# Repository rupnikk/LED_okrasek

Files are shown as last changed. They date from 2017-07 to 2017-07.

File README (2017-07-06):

Urban Rupnik
Zadlog 42
LED_okrasek

-------------------------------------------------------

PCB verzija 1.1 (december 2016)

********SPREMEMBE************
- dovolj velik procesor(ne vem koliko prostora bodo zasedle melodije, tudi zaradi I2C in USART)
- IR oddajnik in sprejemnik (za 36 kHz in 38 kHz)
- en input gumb
- 8 led 
- 1W ojačevalnik
- zvočnik
- porti povezani precej naključno (en prvih tudi programerskih projektov)

PCB verzija 1.2 (januar 2017)
- dovolj velik procesor(ne vem koliko prostora bodo zasedle melodije)
- IR oddajnik in sprejemnik (za 36 kHz in 38 kHz)
- en input gumb
- 8 led 
- 1W ojačevalnik
- zvočnik

********SPREMEMBE************
- BTN na pin 32 (tam je možnost INT, ne samo PCINT)
- IR_REC na pin 1 (tam je možnost INT, ne samo PCINT)
- IR_LED na pin 15 (PB3)(OC2A)(niso iste nastavitve kot pri timerju-0 za AUDIO))(ne na pin 11, zato ker se nastavitev timerja 1 ne bodo mogle prilagajat, zaradi branja daljinca)
-prilagoditev LED-ic

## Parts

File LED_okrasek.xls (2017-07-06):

Reference | Value | Footprint | Datasheet | Farnelll number | Farnell number
LS1 | speaker | LED_okrasek:Speaker | http://www.newark.com/pdfs/datasheets/spc/25R0902.pdf?_ga=1.246424708.1660152525.1481320514 | 2396077
U2 | NCP2890DMR2G | LED_okrasek:Micro8_SMD | http://www.farnell.com/datasheets/1878956.pdf?_ga=1.155430843.1660152525.1481320514 |  | 2464740
C4 | 1u | LED_okrasek:C_0603_HandSoldering
R12 | 10k | LED_okrasek:R_0603_HandSoldering
IC1 | ATMEGA328-A | LED_okrasek:TQFP-32_7x7mm_Pitch0.8mm | http://www.farnell.com/datasheets/2047852.pdf?_ga=1.212856084.1660152525.1481320514 |  | 2443176
R7 | 10k | LED_okrasek:R_0603_HandSoldering
C3 | 1u | LED_okrasek:C_0603_HandSoldering
C2 | 100n | LED_okrasek:C_0603_HandSoldering
R5 | 220 | LED_okrasek:R_0603_HandSoldering
C5 | 1u | LED_okrasek:R_0603_HandSoldering
D2 | LED_Small | LED_okrasek:LED_0_1inch
D3 | LED_Small | LED_okrasek:LED_0_1inch
D4 | LED_Small | LED_okrasek:LED_0_1inch
D5 | LED_Small | LED_okrasek:LED_0_1inch
D9 | LED_Small | LED_okrasek:LED_0_1inch
D6 | LED_Small | LED_okrasek:LED_0_1inch
D7 | LED_Small | LED_okrasek:LED_0_1inch
D8 | LED_Small | LED_okrasek:LED_0_1inch
R6 | 220 | LED_okrasek:R_0603_HandSoldering
R8 | 220 | LED_okrasek:R_0603_HandSoldering
R9 | 220 | LED_okrasek:R_0603_HandSoldering
R11 | 220 | LED_okrasek:R_0603_HandSoldering
R14 | 220 | LED_okrasek:R_0603_HandSoldering
R15 | 220 | LED_okrasek:R_0603_HandSoldering
R16 | 220 | LED_okrasek:R_0603_HandSoldering
R17 | 220 | LED_okrasek:R_0603_HandSoldering
P1 | CONN_01X02 | LED_okrasek:CONN_2x1x5.08
SW1 | SW_PUSH | LED_okrasek:TACTILE_SWTICH_4PIN_SMD | http://www.farnell.com/datasheets/1914518.pdf?_ga=1.147566519.1660152525.1481320514 |  | 2320087
R10 | 220 | LED_okrasek:R_0603_HandSoldering
R13 | 10k | LED_okrasek:R_0603_HandSoldering
PAD1 | PAD | LED_okrasek:PAD
PAD2 | PAD | LED_okrasek:PAD
PAD3 | PAD | LED_okrasek:PAD
D1 | LED_Small | LED_okrasek:R_0805_HandSoldering | http://www.farnell.com/datasheets/1683589.pdf?_ga=1.208456722.1660152525.1481320514 |  | 2290428
R3 | 190 | LED_okrasek:R_0603_HandSoldering
R1 | 1k | LED_okrasek:R_0603_HandSoldering
Q1 | Q_NPN_BEC | LED_okrasek:SOT-23_Handsoldering | http://www.farnell.com/datasheets/1511859.pdf?_ga=1.180667303.1660152525.1481320514 |  | 8737070
PAD4 | PAD | LED_okrasek:PAD
U1 | IR_RECEIVER | LED_okrasek:TSOP | http://www.farnell.com/datasheets/2049972.pdf?_ga=1.122547339.1660152525.1481320514 |  | 2251356
R2 | 220 | LED_okrasek:R_0603_HandSoldering
C1 | 1u | LED_okrasek:C_0603_HandSoldering
R4 | 500 | LED_okrasek:R_0603_HandSoldering
C6 | 1u | LED_okrasek:C_0603_HandSoldering

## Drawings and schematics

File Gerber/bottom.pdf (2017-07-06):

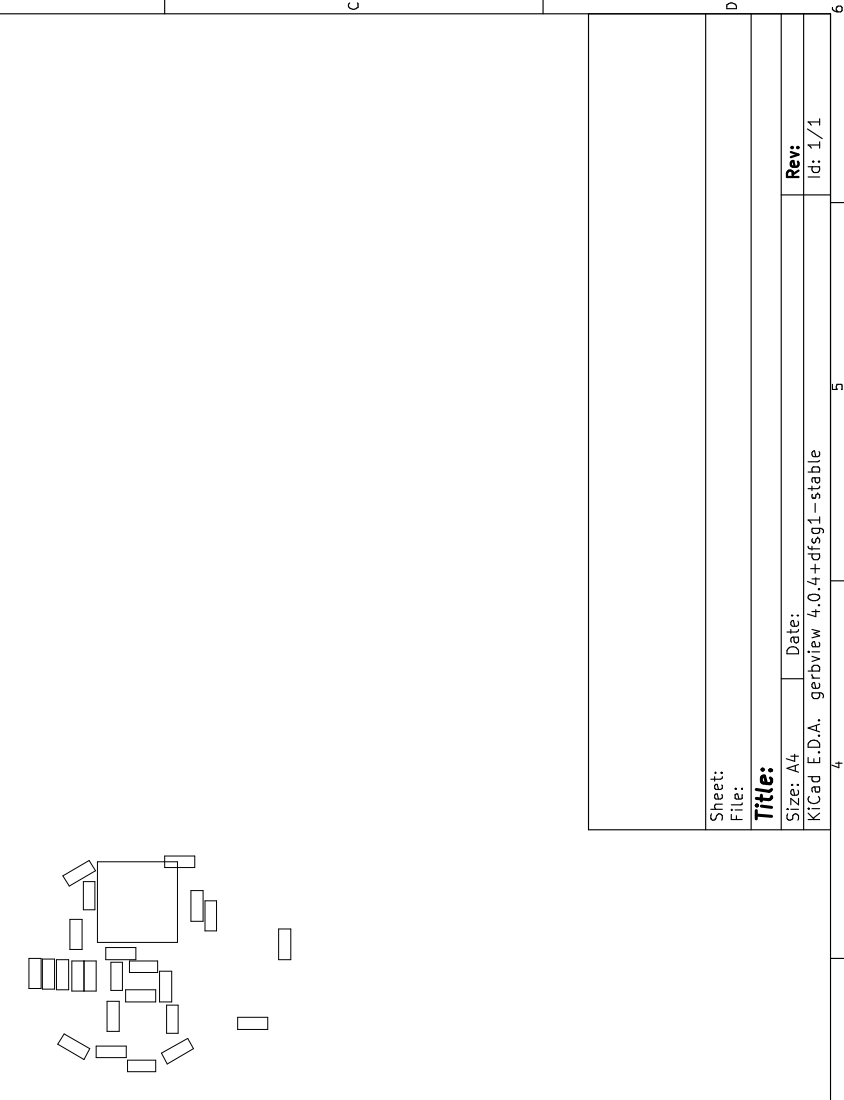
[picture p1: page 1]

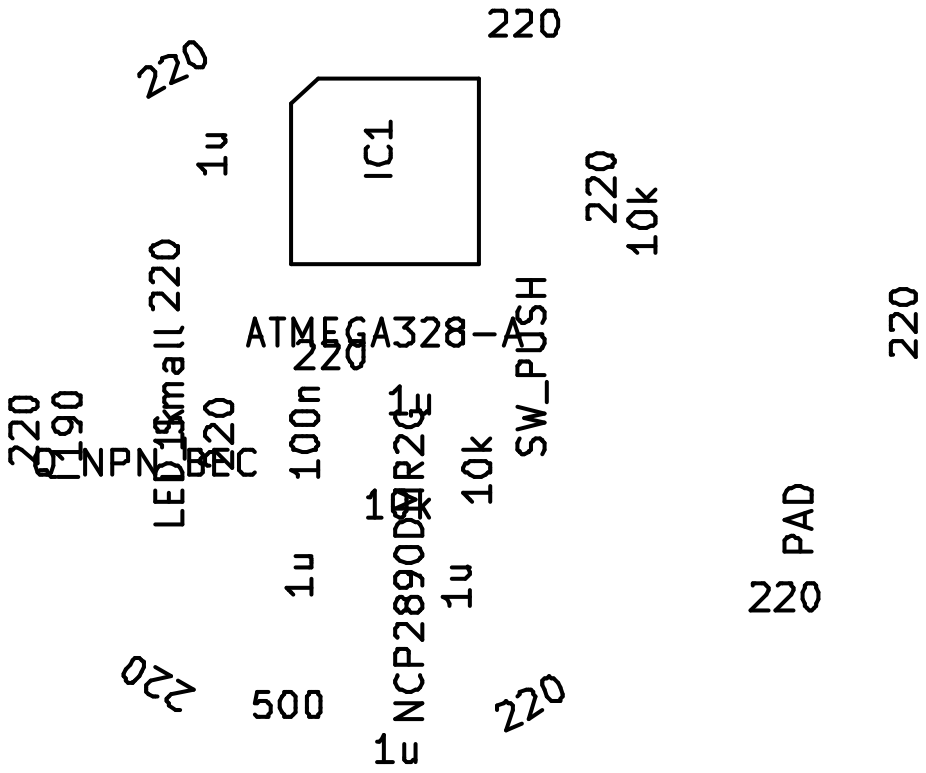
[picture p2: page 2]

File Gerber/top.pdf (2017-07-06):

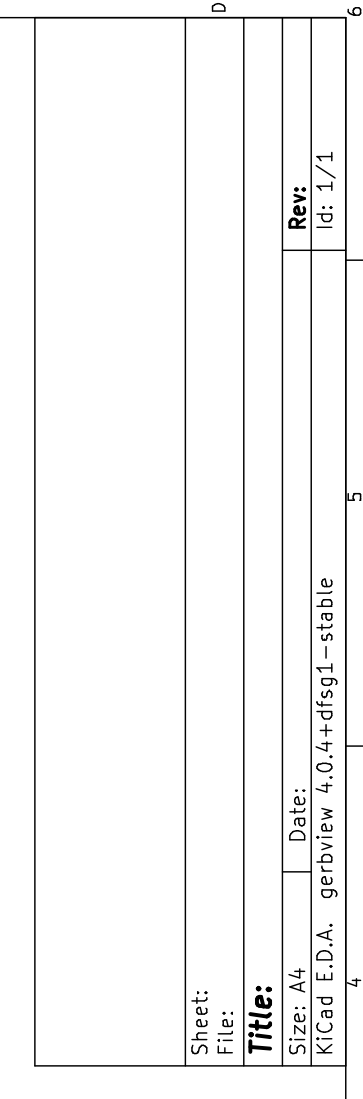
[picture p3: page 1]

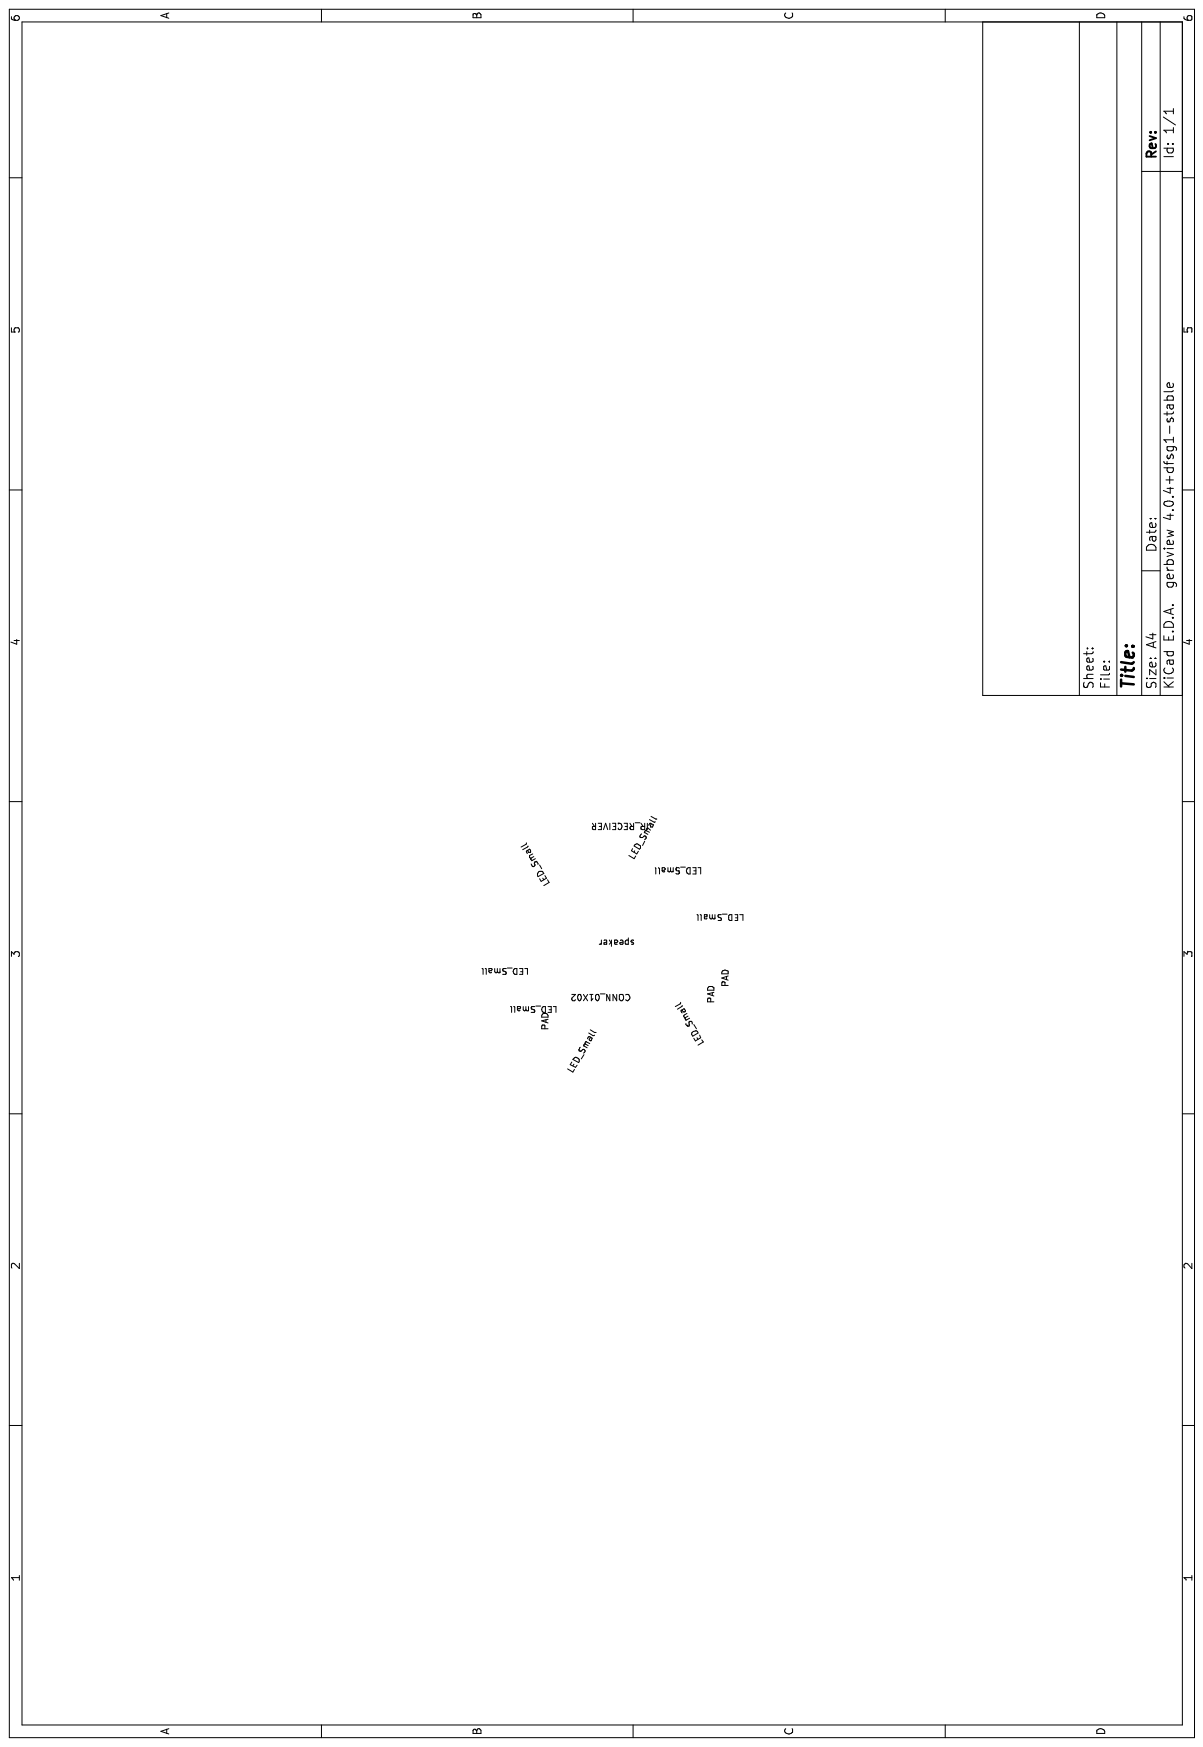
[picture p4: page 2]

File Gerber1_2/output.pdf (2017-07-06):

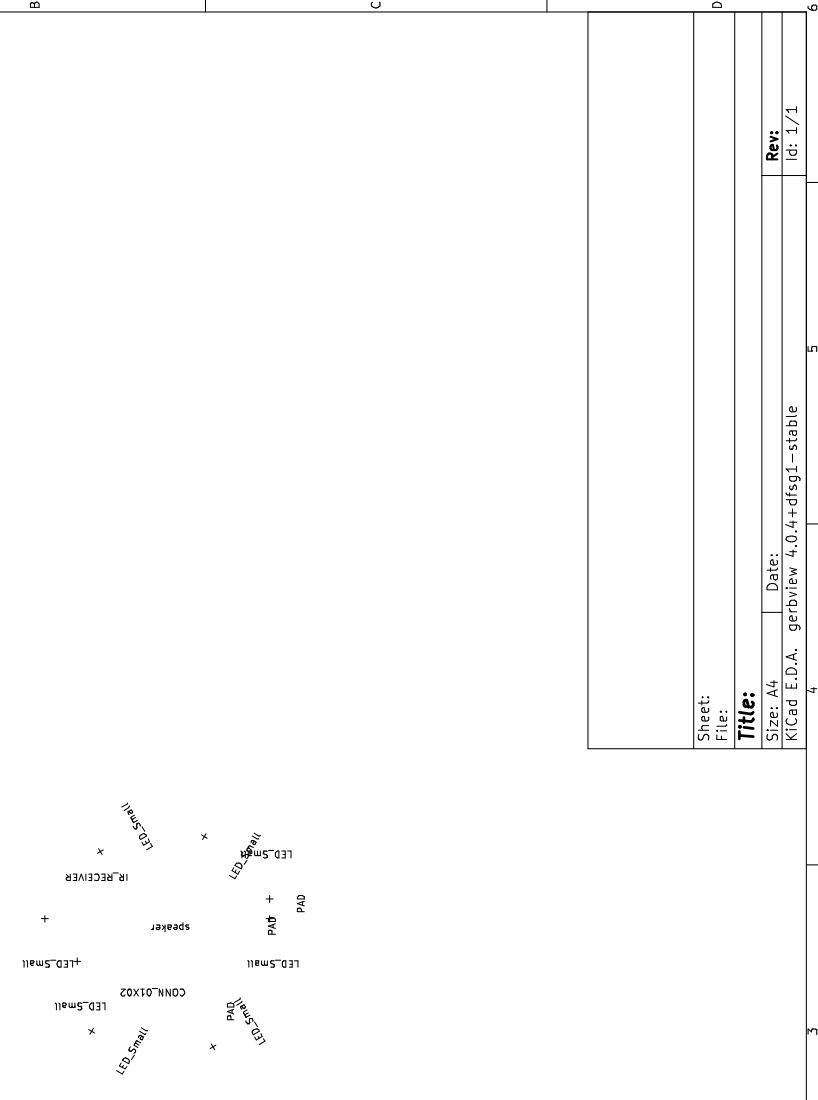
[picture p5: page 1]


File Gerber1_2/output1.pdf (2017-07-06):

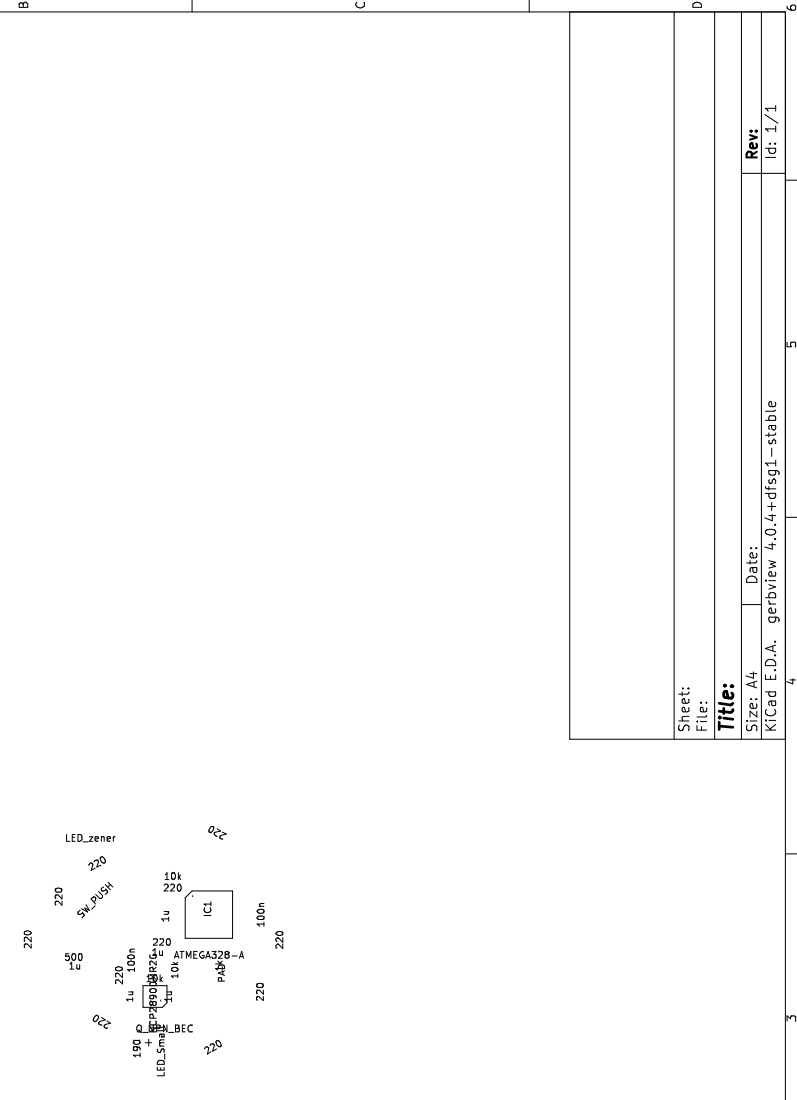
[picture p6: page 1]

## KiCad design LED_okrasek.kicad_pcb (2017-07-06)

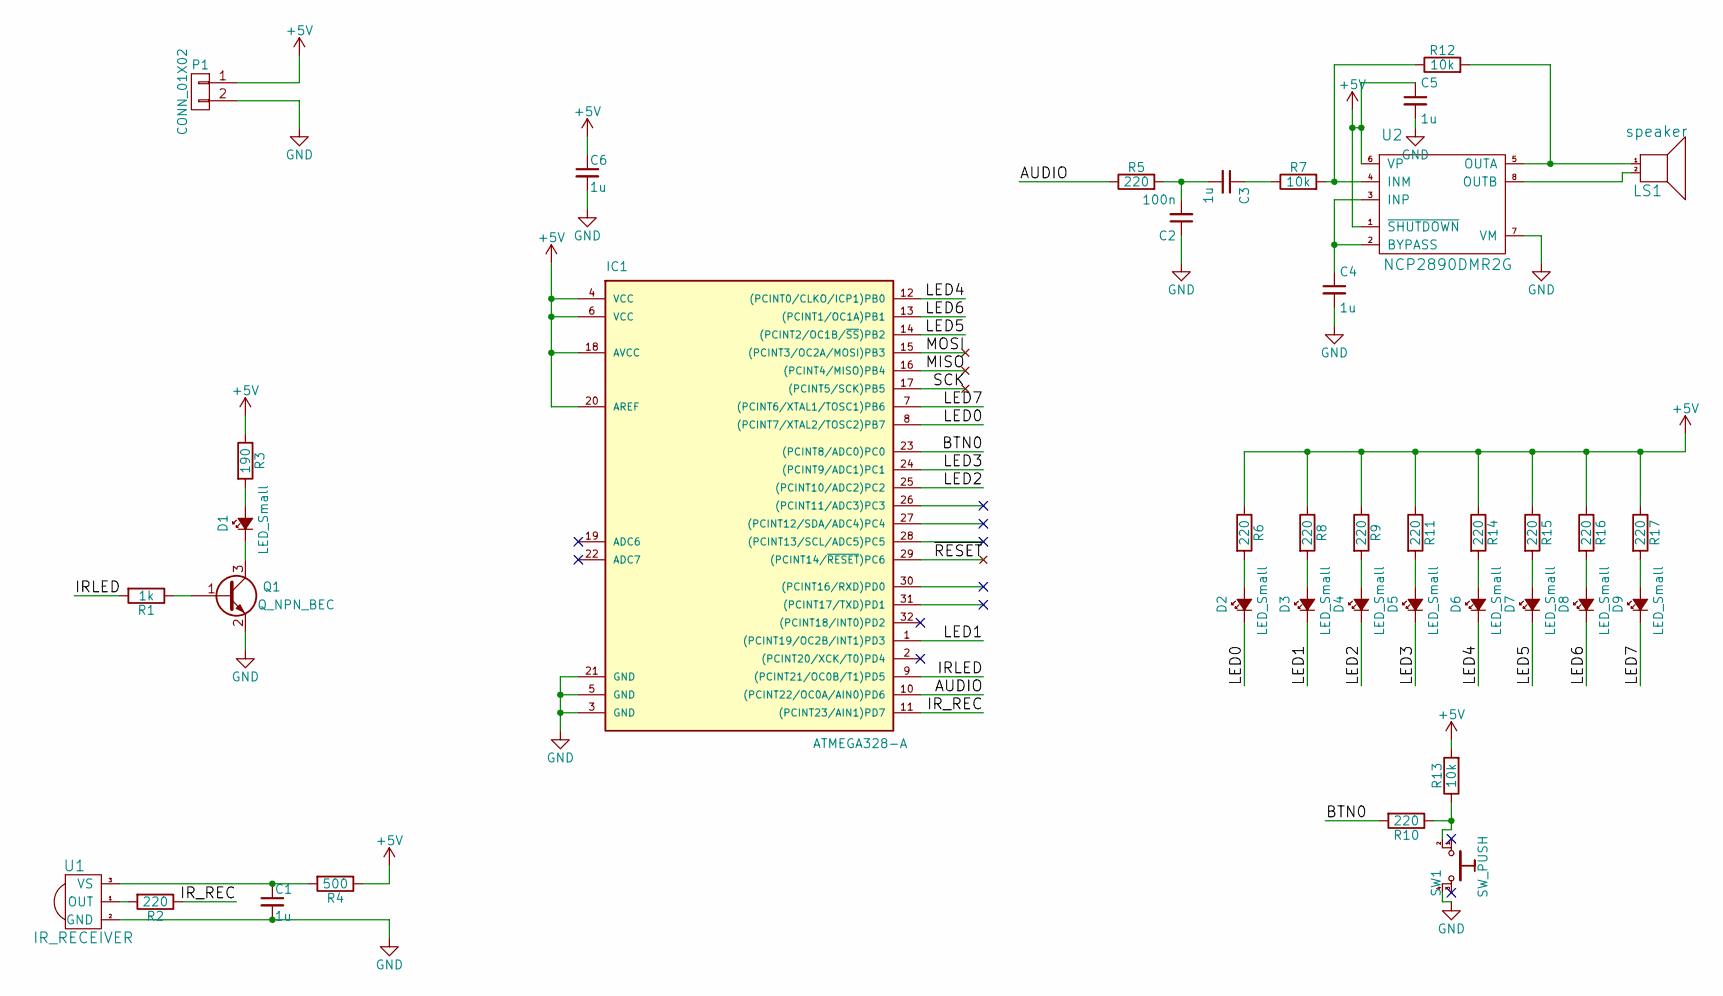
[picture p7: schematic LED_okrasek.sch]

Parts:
C1, C3, C4, C6: 1u; C_0603_HandSoldering
C2: 100n; C_0603_HandSoldering
C5: 1u; R_0603_HandSoldering
D1: LED_Small; R_0603_HandSoldering; Farnell number 2290428
D2, D3, D4, D5, D6, D7, D8, D9: LED_Small; LED_0_1inch
IC1: ATMEGA328-A; TQFP-32_7x7mm_Pitch0.8mm; Farnell number 2443176
LS1: speaker; Speaker; Farnelll number 2396077
P1: CONN_01X02; CONN_2x1x5.08
PAD1, PAD2, PAD3, PAD4: PAD
Q1: Q_NPN_BEC; SOT-23_Handsoldering; Farnell number 8737070
R1: 1k; R_0603_HandSoldering
R2, R5, R6, R8, R9, R10, R11, R14, R15, R16, R17: 220; R_0603_HandSoldering
R3: 190; R_0603_HandSoldering
R4: 500; R_0603_HandSoldering
R7, R12, R13: 10k; R_0603_HandSoldering
SW1: SW_PUSH; TACTILE_SWTICH_4PIN_SMD
U1: IR_RECEIVER; TSOP; Farnell number 2251356
U2: NCP2890DMR2G; Micro8_SMD; Farnell number 2464740

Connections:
+5V: C5.1, C6.1, IC1.4 (VCC), IC1.6 (VCC), IC1.18 (AVCC), IC1.20 (AREF), P1.1, R3.1, R4.1, R6.1, R8.1, R9.1, R11.1, R13.2, R14.1, R15.1, R16.1, R17.1, U2.1 (~SHUTDOWN), U2.6 (VP)
/AUDIO: IC1.10 ((PCINT22/OC0A/AIN0)PD6), R5.1
/BTN0: IC1.23 ((PCINT8/ADC0)PC0), R10.2
/IRLED: IC1.9 ((PCINT21/OC0B/T1)PD5), R1.2
/IR_REC: IC1.11 ((PCINT23/AIN1)PD7), R2.1
/LED0: D2.1 (K), IC1.8 ((PCINT7/XTAL2/TOSC2)PB7)
/LED1: D3.1 (K), IC1.1 ((PCINT19/OC2B/INT1)PD3)
/LED2: D4.1 (K), IC1.25 ((PCINT10/ADC2)PC2)
/LED3: D5.1 (K), IC1.24 ((PCINT9/ADC1)PC1)
/LED4: D6.1 (K), IC1.12 ((PCINT0/CLKO/ICP1)PB0)
/LED5: D7.1 (K), IC1.14 ((PCINT2/OC1B/~SS~)PB2)
/LED6: D8.1 (K), IC1.13 ((PCINT1/OC1A)PB1)
/LED7: D9.1 (K), IC1.7 ((PCINT6/XTAL1/TOSC1)PB6)
/MISO: IC1.16 ((PCINT4/MISO)PB4), PAD2.1
/MOSI: IC1.15 ((PCINT3/OC2A/MOSI)PB3), PAD1.1
/SCK: IC1.17 ((PCINT5/SCK)PB5), PAD3.1
/~RESET: IC1.29 ((PCINT14/~RESET~)PC6), PAD4.1
GND: C1.2, C2.1, C4.2, C5.2, C6.2, IC1.3 (GND), IC1.5 (GND), IC1.21 (GND), P1.2, Q1.2 (E), SW1.4, U1.2 (GND), U2.7 (VM)
unnamed: C1.1, R4.2, U1.3 (VS)
unnamed: C2.2, C3.2, R5.2
unnamed: C3.1, R7.1
unnamed: C4.1, U2.2 (BYPASS), U2.3 (INP)
unnamed: D1.1 (K), Q1.3 (C)
unnamed: D1.2 (A), R3.2
unnamed: D2.2 (A), R6.2
unnamed: D3.2 (A), R8.2
unnamed: D4.2 (A), R9.2
unnamed: D5.2 (A), R11.2
unnamed: D6.2 (A), R14.2
unnamed: D7.2 (A), R15.2
unnamed: D8.2 (A), R16.2
unnamed: D9.2 (A), R17.2
unnamed: LS1.1 (A), R12.2, U2.5 (OUTA)
unnamed: LS1.2 (B), U2.8 (OUTB)
unnamed: Q1.1 (B), R1.1
unnamed: R2.2, U1.1 (OUT)
unnamed: R10.1, R13.1, SW1.2
unnamed: R7.2, R12.1, U2.4 (INM)

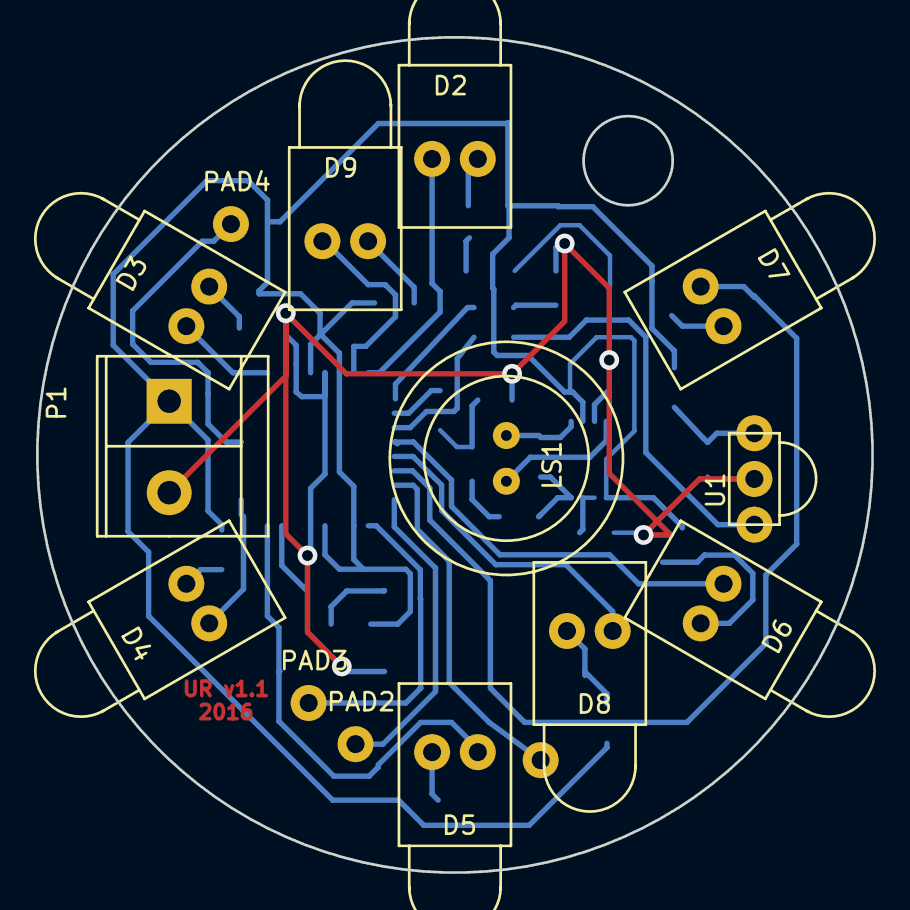
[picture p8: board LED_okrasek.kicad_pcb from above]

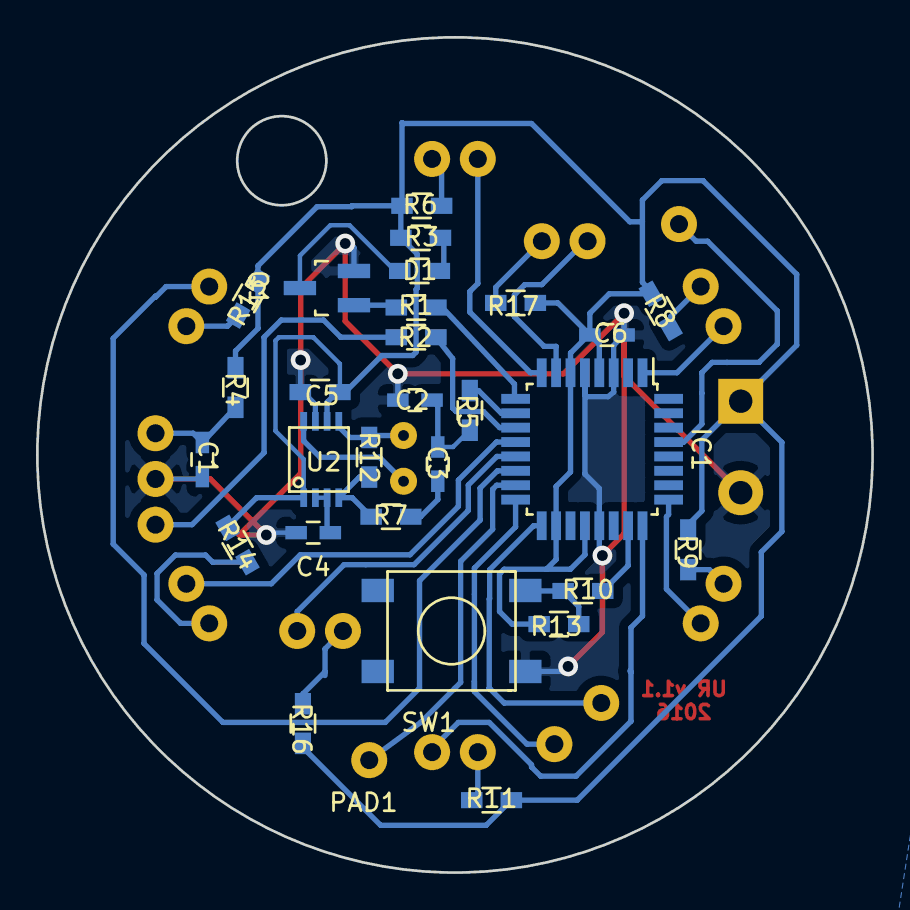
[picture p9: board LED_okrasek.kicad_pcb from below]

Board: 2 copper layers, 46.4 x 46.4 mm, 43 parts (29 on the bottom side), 38 nets.

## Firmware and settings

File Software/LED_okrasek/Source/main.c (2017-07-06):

/*
 * main.c
 *
 *  Created on: 27. dec. 2016
 *      Author: Urban Rupnik
 *      City: Zadlog 42
 */


#include "led_okrasek.h"

uint8_t ir();

typedef enum{
	IDLE,
//	STARTBIT,
	REPEATBIT,
	READINGPREP,
	READING,
	VERIFY,
	DECODE
}state_machine;

typedef enum{
	SONG,
	CLEAR,
	BLINK_ALL,
	CIRCLE,
	CIRCLE1,
	RAND
}light_machine;

typedef enum{
	STOP,
	PLAY,
	PAUSE
}play_state;

uint8_t song_flag=0;
uint8_t light_flag=1;

uint16_t time=0;
uint32_t irval;
uint32_t *irval_p=&irval;
uint8_t prev=1;
uint8_t bitcnt=0;
uint8_t contr=0x00;
uint8_t count_ovr1=0;
uint32_t count_ovr2=0;
uint32_t delay_cnt=0;
state_machine my_state_machine = IDLE;
light_machine my_light=SONG;
play_state music=STOP;
//circ_state


int main(){

	uint32_t tempo=40;
	   IOCfg();
	 uint8_t song=0;
	   PWMCfg();
	   uint8_t a=0;

	   IntCfg();
//	   TIMER2_STOP;
//	   TCNT2=0;
	   PWM1_64_PRESC;
	   PWM2_8_PRESC;
	   OCR2B=99;
	   SETBIT(TIMSK1,TOIE1);
	   SETBIT(TIMSK2,OCIE2B);

	   sei();
	   uint32_t i=0;
	   uint32_t tim=0;

	   for(;;){
		switch(my_state_machine){
			case IDLE:
				break;
			case DECODE:
				if(contr >= 0 && contr < NUM_SONGS){
					song=contr;
					light_flag=0;
					//i=song_indeces[song];
					song_flag=0;
					i=pgm_read_word(&song_indeces[song]);
				}
				if(contr==8){
					light_flag=!light_flag;
				}
				else if(contr==14){
					song_flag=!song_flag;
					light_flag=song_flag;
				}
				else if(contr==12) CLEARBIT(LED6_PORT, LED6);
				else;
				my_light=SONG;
				my_state_machine=IDLE;
				break;
		}

		switch(my_light){
			case SONG:
				for (uint8_t n=0; n<LED_NUM;n++){
					if(n==song)leds[n].value=0;
					else leds[n].value=1;
					SetValue(&leds[n]);
				}
				my_light=CLEAR;
				break;
			case CLEAR:
				if(light_flag==1){
					for (uint8_t n=0; n<LED_NUM;n++){
						leds[n].value=1;
						SetValue(&leds[n]);
					}

					my_light=rand()%5+1;
				}
				break;
			case BLINK_ALL:
				if(count_ovr2>3500){
				count_ovr2=0;
				for (uint8_t n=0; n<LED_NUM;n++){

					leds[n].value= !leds[n].value;
					SetValue(&leds[n]);
				}
				}
				if(count_ovr1>10){
					my_light=CLEAR;
					count_ovr1=0;
				}
				break;
			case CIRCLE:
				if(count_ovr2>300){
				count_ovr2=0;
					if (a==0){
						leds[a].value=0;
						leds[5].value=1;
					}
					else{
						leds[a].value=0;
						leds[a-1].value=1;
					}
					for (uint8_t n=0; n<LED_NUM;n++){
						SetValue(&leds[n]);
					}
					if(a==5)a=0;
					else a++;
				}
				if(count_ovr1>10){

					my_light=CLEAR;
					count_ovr1=0;
				}
				break;
			case CIRCLE1:
				if(count_ovr2>300){
				count_ovr2=0;
					leds[a].value=!leds[a].value;
					for (uint8_t n=0; n<LED_NUM;n++){
						SetValue(&leds[n]);
					}
					if(a==5)a=0;
					else a++;
				}
				if(count_ovr1>10){

					my_light=CLEAR;
					count_ovr1=0;
				}
				break;

			case RAND:
				if(count_ovr2>500){
				count_ovr2=0;
				leds[rand()%8].value=rand()%2;
					for (uint8_t n=0; n<LED_NUM;n++){
						SetValue(&leds[n]);
					}
				}
				if(count_ovr1>10){

					my_light=CLEAR;
					count_ovr1=0;
				}
				break;
		}

		//playnote(64,pgm_read_word(p[0][0][0]),2000);
//			while(pgm_read_word(&kuza_pazi_song[i][2]) && song_flag==1){
//						playnote(pgm_read_word(&kuza_pazi_song[i][1]),pgm_read_word(&kuza_pazi_song[i][0]),pgm_read_word(&kuza_pazi_song[i][2])*tempo);
//						//playnote(A3_PRESC, A3, 4000);
//						i++;
//					}
		switch(music){
			case STOP:
			//	if(pgm_read_word(&cuk_song[i][2])!=0 && song_flag==1){
				if(i<pgm_read_word(&song_indeces[song+1]) && song_flag==1){
					//playnote(pgm_read_word(&cuk_song[i][1]),pgm_read_word(&cuk_song[i][0]),pgm_read_word(&cuk_song[i][2])*tempo);
					playnote(pgm_read_word(&songs[i][1]),pgm_read_word(&songs[i][0]));
					delay_cnt=0;
					TCNT2=0;
					tim=pgm_read_word(&songs[i][2])*tempo;
					music=PLAY;
				}
				else{
					i=pgm_read_word(&song_indeces[song])+1;
					tempo=pgm_read_word(&songs[i-1][0]);
				}

				break;
			case PLAY:
				if(delay_cnt >= tim || song_flag==0){
					TIMER0_STOP;
					delay_cnt=0;
					TCNT2=0;
					i++;
					music=PAUSE;
				}
				if(i==pgm_read_word(&song_indeces[song+1])){
				   i=pgm_read_word(&song_indeces[song]);
				   song_flag=0;
				   music=STOP;
				}
				break;
			case PAUSE:
				if(delay_cnt >= 10){
					music=STOP;
				}
				break;
			}
		}
	return 0;
}



ISR(PCINT1_vect){
	if(!BITVAL(PINC, BTN)){
		song_flag=!song_flag;
		light_flag=song_flag;
	}
}

ISR(TIMER1_OVF_vect){
	count_ovr1++;
}

ISR(TIMER2_COMPB_vect){
	count_ovr2++;
	delay_cnt++;
}

ISR(PCINT2_vect){
	TOGGLEBIT(LED3_PORT, LED3);
	time = TCNT1;
	PWM1_64_PRESC;
	TCNT1=0;
	ir();
}

uint8_t ir(){
	switch(my_state_machine){
		case IDLE:
			if(time > 1060 && time < 1200){
				my_state_machine=REPEATBIT;
			}
			else{
				my_state_machine=IDLE;
			}
			break;
		case REPEATBIT:
			if(time > 500 && time < 625){
				my_state_machine=READINGPREP;
				bitcnt=0;
				*irval_p=0x00000000;
				contr=0x00;
			}
			else{
				my_state_machine=IDLE;
			}
			break;
		case READINGPREP:
			if(time > 45 && time < 90){
				my_state_machine=READING;

			}
			else{
				my_state_machine=IDLE;
			}
			break;
		case READING:
			if(time > 45 && time < 90){
				my_state_machine=READINGPREP;
			}
			else if(time > 150 && time < 250){
				*irval_p |= (1 << bitcnt);
			if(bitcnt>=16 && bitcnt <24)contr|=(1 << (bitcnt-16));
				my_state_machine=READINGPREP;
			}
			else{
				my_state_machine=IDLE;
			}
			if(bitcnt==31){

				my_state_machine=VERIFY;
			}
			else{
				bitcnt++;
			}
			break;
		case VERIFY:
			if(1){
				my_state_machine=DECODE;
				return 1;
			}
			break;
	}
	return 0;
}

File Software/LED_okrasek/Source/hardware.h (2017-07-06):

/*
 * hardware.h
 *
 *  Created on: 19. dec. 2016
 *      Author: Urban Rupnik
 *      City: Zadlog 42
 */
#include <avr/io.h>

#ifndef _HARDWARE_H_
#define _HARDWARE_H_



/*******************************
 *************LEDICE************
 *******************************/
#define LED0 PB7
#define LED1 PD3
#define LED2 PC2
#define LED3 PC1
#define LED4 PB0
#define LED5 PB2
#define LED6 PB1
#define LED7 PB6

#define LED0_PORT PORTB
#define LED1_PORT PORTD
#define LED2_PORT PORTC
#define LED3_PORT PORTC
#define LED4_PORT PORTB
#define LED5_PORT PORTB
#define LED6_PORT PORTB
#define LED7_PORT PORTB


#define LED0_DIR_PORT DDRB
#define LED1_DIR_PORT DDRD
#define LED2_DIR_PORT DDRC
#define LED3_DIR_PORT DDRC
#define LED4_DIR_PORT DDRB
#define LED5_DIR_PORT DDRB
#define LED6_DIR_PORT DDRB
#define LED7_DIR_PORT DDRB

#define LED5_PWM OC1B
#define LED5_PWM_CTR_REG TCCR1A

/*******************************
 ************ZVOČNIK************
 *******************************/
#define AUDIO PD6
#define AUDIO_PORT	PORTD
#define AUDIO_DIR_PORT	DDRD
#define AUDIO_PWM



/*******************************
 *************IR LED************
 *******************************/
#define IR_LED PD5
#define IR_LED_PORT	PORTD
#define IR_LED_DIR_PORT	DDRD



/*******************************
 ***********IR RECEIVER*********
 *******************************/

#define IR_REC PD7
#define IR_REC_PORT	PORTD
#define IR_REC_DIR_PORT	DDRD
#define IR_REC_VALUE_REG PIND
#define IR_REC_PCINT PCINT23

/*******************************
 *************BUTTON************
 *******************************/
#define BTN PC0
#define BTN_PORT PORTC
#define BTN_DIR_PORT DDRC
#define BTN_VALUE_REG PINC
#define BTN_PCINT PCINT8


#endif
